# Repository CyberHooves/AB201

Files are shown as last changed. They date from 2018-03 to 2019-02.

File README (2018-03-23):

Haos Redro
==========

README for AB201
----------------

The AB201 is a class-AB audio amplifier module designed to have a sufficiently low profile to fit into 1U rack-mounting cases. It has been designed to provide up to 200W RMS output power before clipping. Output powers of up to 300W may be possible with sufficient cooling but is NOT reccommended with the specified heatsink (Fischer Electronic SK499 profile)

Notes on cooling:
-----------------
This module requires forced air cooling. The enclosure into which this module is installed must be designed to move air through the heatsink. There is provision for a two-lead temperature sensor for fan control and a TO-220 packaged NC thermostat to disconnect the output in case of overheating.

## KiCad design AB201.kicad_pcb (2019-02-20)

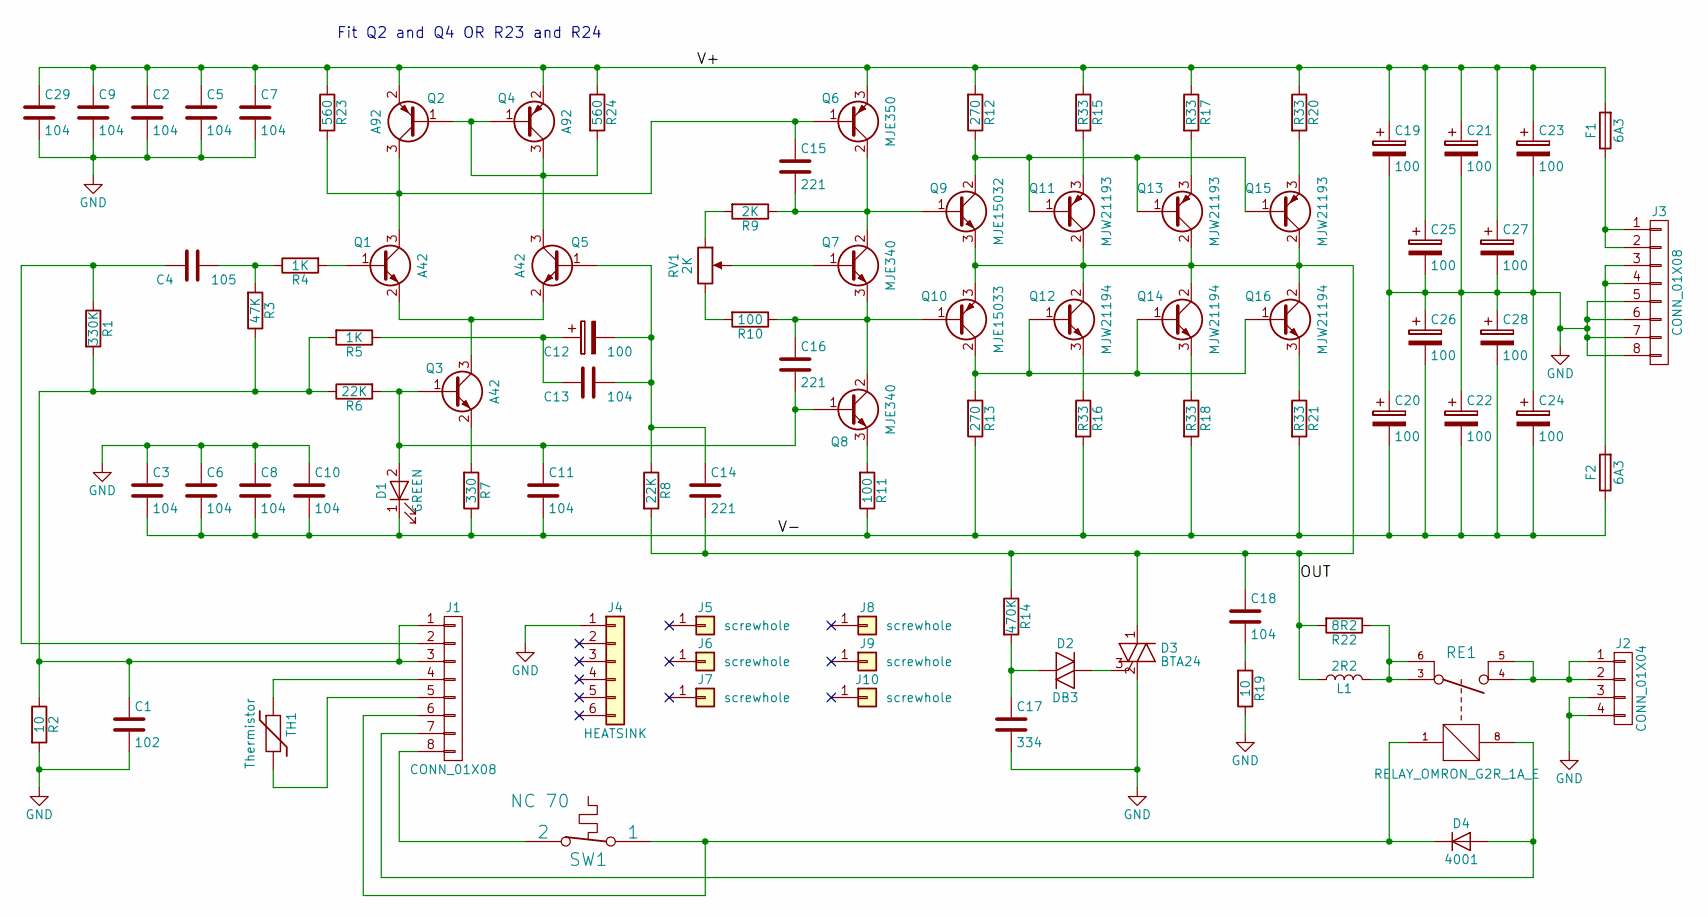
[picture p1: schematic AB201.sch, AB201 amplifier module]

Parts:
C1: 102; C_0805
C2, C3, C5, C6, C7, C8, C9, C10, C11, C29: 104; C_0805
C4: 105; C_Rect_L7.2mm_W5.5mm_P5.00mm_FKS2_FKP2_MKS2_MKP2
C12: 100; CP_Radial_D6.3mm_P2.50mm
C13: 104; C_Rect_L7.2mm_W3.0mm_P5.00mm_FKS2_FKP2_MKS2_MKP2
C14, C15, C16: 221; C_0805
C17: 334; C_0805
C18: 104; C_Rect_L7.2mm_W5.5mm_P5.00mm_FKS2_FKP2_MKS2_MKP2
C19, C20, C21, C22, C23, C24, C25, C26, C27, C28: 100; CP_Radial_D10.0mm_P5.00mm
D1: GREEN; LED_0805
D2: DB3; D_MiniMELF
D3: BTA24; TO-220-3_Vertical
D4: 4001; D_SMA
F1, F2: 6A3; Fuseholder5x20_horiz_open_universal_Type-III
J1: CONN_01X08; Pin_Header_Straight_2x04_Pitch2.54mm
J2: CONN_01X04; Molex_MiniFit-JR-5556-04A_2x02x4.20mm_Straight
J3: CONN_01X08; Molex_MiniFit-JR-5556-08A_2x04x4.20mm_Straight
J4: HEATSINK; HS-FISCHER-SK499-200-6A
J5, J6, J7, J8, J9, J10: screwhole; MH-H3.2-P7
L1: 2R2; Choke_SMD_10.4x10.4_H4.8
Q1, Q3, Q5: A42; SOT-23
Q2, Q4: A92; SOT-23
Q6: MJE350; TO-126_Vertical
Q7, Q8: MJE340; TO-126_Vertical
Q9: MJE15032; TO-220-3_Vertical
Q10: MJE15033; TO-220-3_Vertical
Q11, Q13, Q15: MJW21193; TO-247_TO-3P_Vertical
Q12, Q14, Q16: MJW21194; TO-247_TO-3P_Vertical
R1: 330K; R_0805
R2: 10; R_0805
R3: 47K; R_0805
R4, R5: 1K; R_0805
R6, R8: 22K; R_0805
R7: 330; R_0805
R9: 2K; R_0805
R10, R11: 100; R_0805
R12, R13: 270; R_1218
R14: 470K; R_0805
R15, R16, R17, R18, R20, R21: R33; R_Radial_Power_L13.0mm_W9.0mm_P5.00mm
R19: 10; R_Axial_DIN0922_L20.0mm_D9.0mm_P7.62mm_Vertical
R22: 8R2; R_Axial_Power_L20.0mm_W6.4mm_P7.62mm_Vertical
R23, R24: 560; R_0805
RE1: RELAY_OMRON_G2R_1A_E; RELAY-OMRON-G2R-1A-E
RV1: 2K; Potentiometer_Trimmer_Bourns_3296W
SW1: NC 70; TO-220-2_Vertical
TH1: Thermistor; PINHEAD1-2

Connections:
/OUT: C14.2, C18.1, D3.1 (A1), L1.1, Q9.3 (E), Q10.3 (E), Q11.2 (C), Q12.2 (C), Q13.2 (C), Q14.2 (C), Q15.2 (C), Q16.2 (C), R8.2, R14.1, R22.2
/V+: C2.1, C5.1, C7.1, C9.1, C19.1, C21.1, C23.1, C25.1, C27.1, C29.1, F1.2, Q2.2 (E), Q4.2 (E), Q6.3 (E), R12.2, R15.1, R17.1, R20.1, R23.1, R24.1
/V-: C3.2, C6.2, C8.2, C10.2, C11.2, C20.2, C22.2, C24.2, C26.2, C28.2, D1.1 (K), F2.1, R7.1, R11.1, R13.1, R16.2, R18.2, R21.2
GND: C1.2, C2.2, C3.1, C5.2, C6.1, C7.2, C8.1, C9.2, C10.1, C17.2, C19.2, C20.1, C21.2, C22.1, C23.2, C24.1, C25.2, C26.1, C27.2, C28.1, C29.2, D3.2 (A2), J2.3, J2.4, J3.5, J3.6, J3.7, J3.8, J4.1, R2.2, R19.1
unnamed: C1.1, J1.1, J1.3, R1.2, R2.1, R3.1, R5.2, R6.1
unnamed: C4.1, J1.2, R1.1
unnamed: C4.2, R3.2, R4.1
unnamed: C11.1, C16.2, D1.2 (A), Q3.1 (B), Q8.1 (B), R6.2
unnamed: C12.1, C13.1, R5.1
unnamed: C12.2, C13.2, C14.1, Q5.1 (B), R8.1
unnamed: C15.1, Q1.3 (C), Q2.3 (C), Q6.1 (B), R23.2
unnamed: C15.2, Q6.2 (C), Q7.2 (C), Q9.1 (B), R9.1
unnamed: C16.1, Q7.3 (E), Q8.2 (C), Q10.1 (B), R10.1
unnamed: C17.1, D2.1 (K), R14.2
unnamed: C18.2, R19.2
unnamed: D2.2 (A), D3.3 (G)
unnamed: D4.1 (K), J1.6, RE1.1 (C1), SW1.1
unnamed: D4.2 (A), J1.7, RE1.8 (C2)
unnamed: F1.1, J3.1, J3.2
unnamed: F2.2, J3.3, J3.4
unnamed: J1.4, TH1.1
unnamed: J1.5, TH1.2
unnamed: J1.8, SW1.2
unnamed: J2.1, J2.2, RE1.4, RE1.5
unnamed: L1.2, R22.1, RE1.3, RE1.6
unnamed: Q1.1 (B), R4.2
unnamed: Q1.2 (E), Q3.3 (C), Q5.2 (E)
unnamed: Q2.1 (B), Q4.1 (B), Q4.3 (C), Q5.3 (C), R24.2
unnamed: Q3.2 (E), R7.2
unnamed: Q7.1 (B), RV1.2
unnamed: Q8.3 (E), R11.2
unnamed: Q10.2 (C), Q12.1 (B), Q14.1 (B), Q16.1 (B), R13.2
unnamed: Q9.2 (C), Q11.1 (B), Q13.1 (B), Q15.1 (B), R12.1
unnamed: Q11.3 (E), R15.2
unnamed: Q12.3 (E), R16.1
unnamed: Q13.3 (E), R17.2
unnamed: Q14.3 (E), R18.1
unnamed: Q15.3 (E), R20.2
unnamed: Q16.3 (E), R21.1
unnamed: R9.2, RV1.1
unnamed: R10.2, RV1.3

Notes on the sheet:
Fit Q2 and Q4 OR R23 and R24

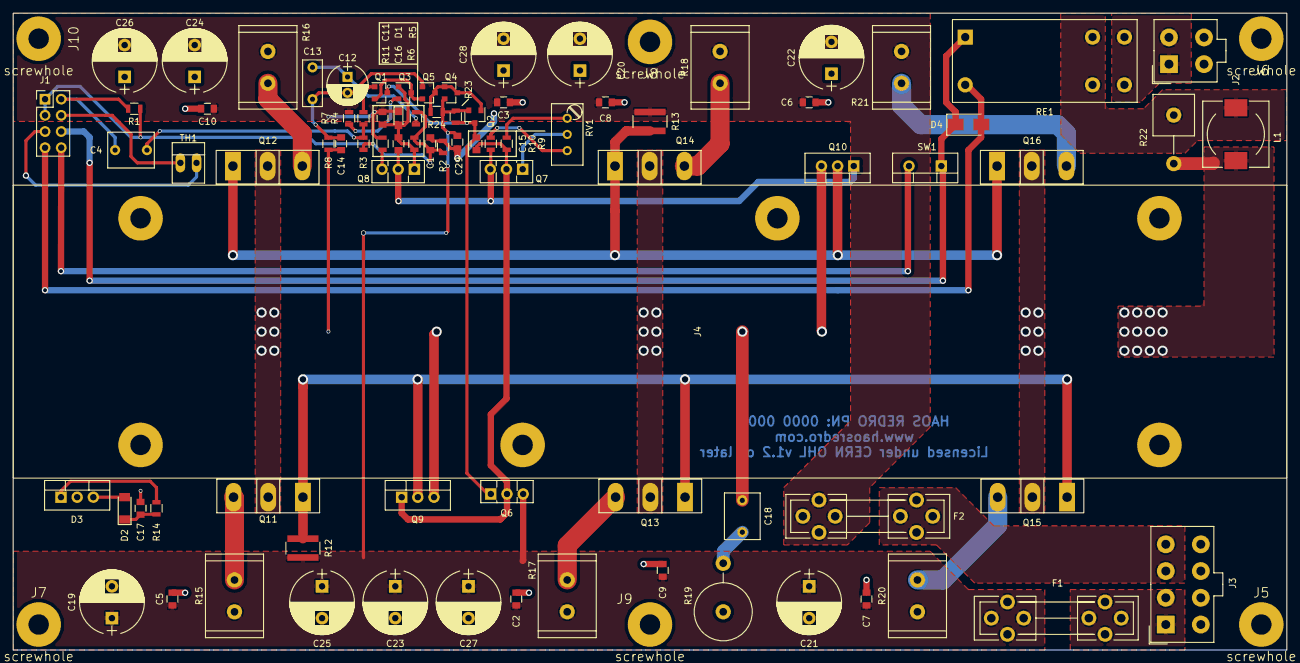
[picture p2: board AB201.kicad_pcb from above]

Board: 2 copper layers, 200.0 x 100.0 mm, 90 parts (0 on the bottom side), 41 nets.

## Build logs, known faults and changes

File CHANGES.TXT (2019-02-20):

20/02/2019: PCB changes
=======================
Routing cleanup

16/04/2018: PCB changes
=======================
Silkscreen text moved to bottom copper layer
Minor trace rerouting

21/03/2018: Initial release
===========================
Please note that this is a testing release and may not be suitable for production use.

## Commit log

2018-04-16 PCB layout updated
    [AB201.kicad_pcb]
2019-02-20 PCB changes
    [AB201.kicad_pcb, AB201.sch]

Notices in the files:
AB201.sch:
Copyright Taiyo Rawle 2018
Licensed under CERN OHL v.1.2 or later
